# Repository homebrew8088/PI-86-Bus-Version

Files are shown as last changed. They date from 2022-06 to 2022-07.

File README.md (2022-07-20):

# PI-86-Bus-Version
8088 V20 Raspberry Pi "hat"
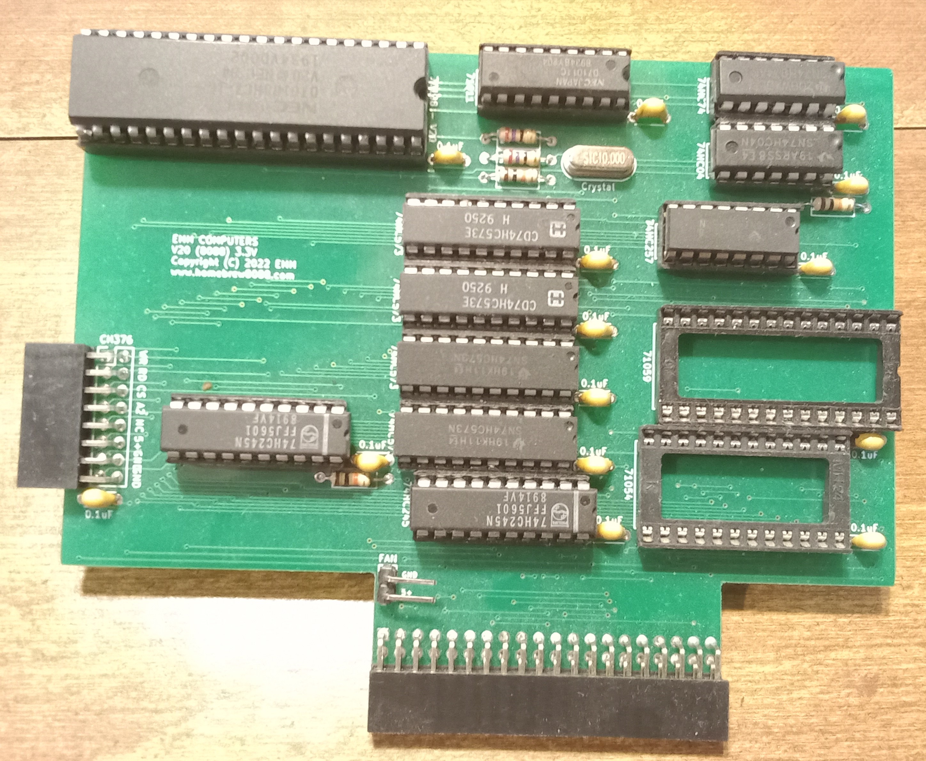
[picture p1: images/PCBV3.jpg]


\
\
This is a repository for my 8088 Raspberry Pi "hat" This is the 3rd version of this project and is quite different than previous versions. The intent was to achieve faster processing speeds by allowing the 8088 to run at its own speed. 

**Homepage**\
https://www.homebrew8088.com/

**Join the discussion group on Discord**\
https://discord.gg/AswNqwpRGP

**eBay store**\
http://www.ebay.com/sch/emil6190/m.html

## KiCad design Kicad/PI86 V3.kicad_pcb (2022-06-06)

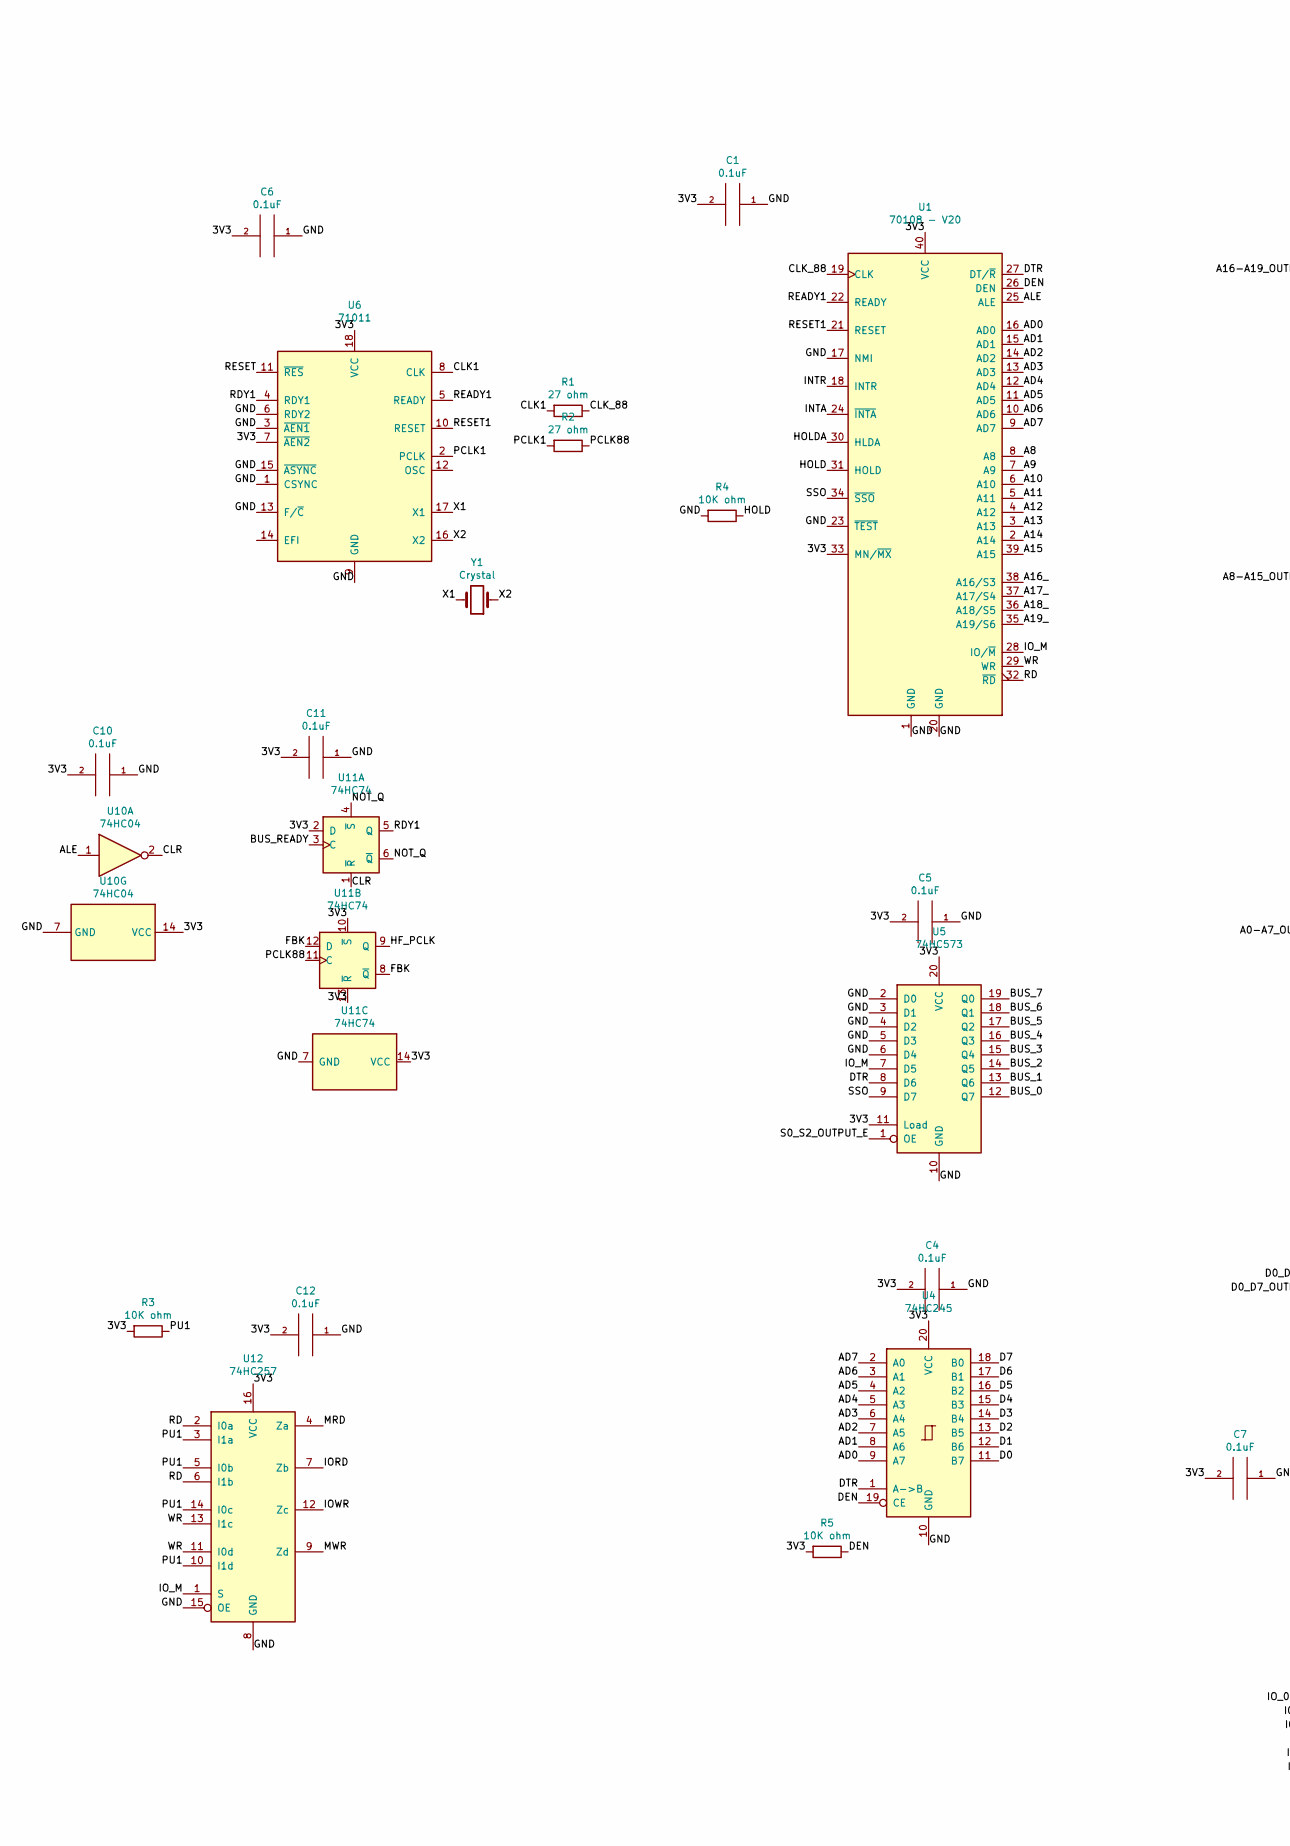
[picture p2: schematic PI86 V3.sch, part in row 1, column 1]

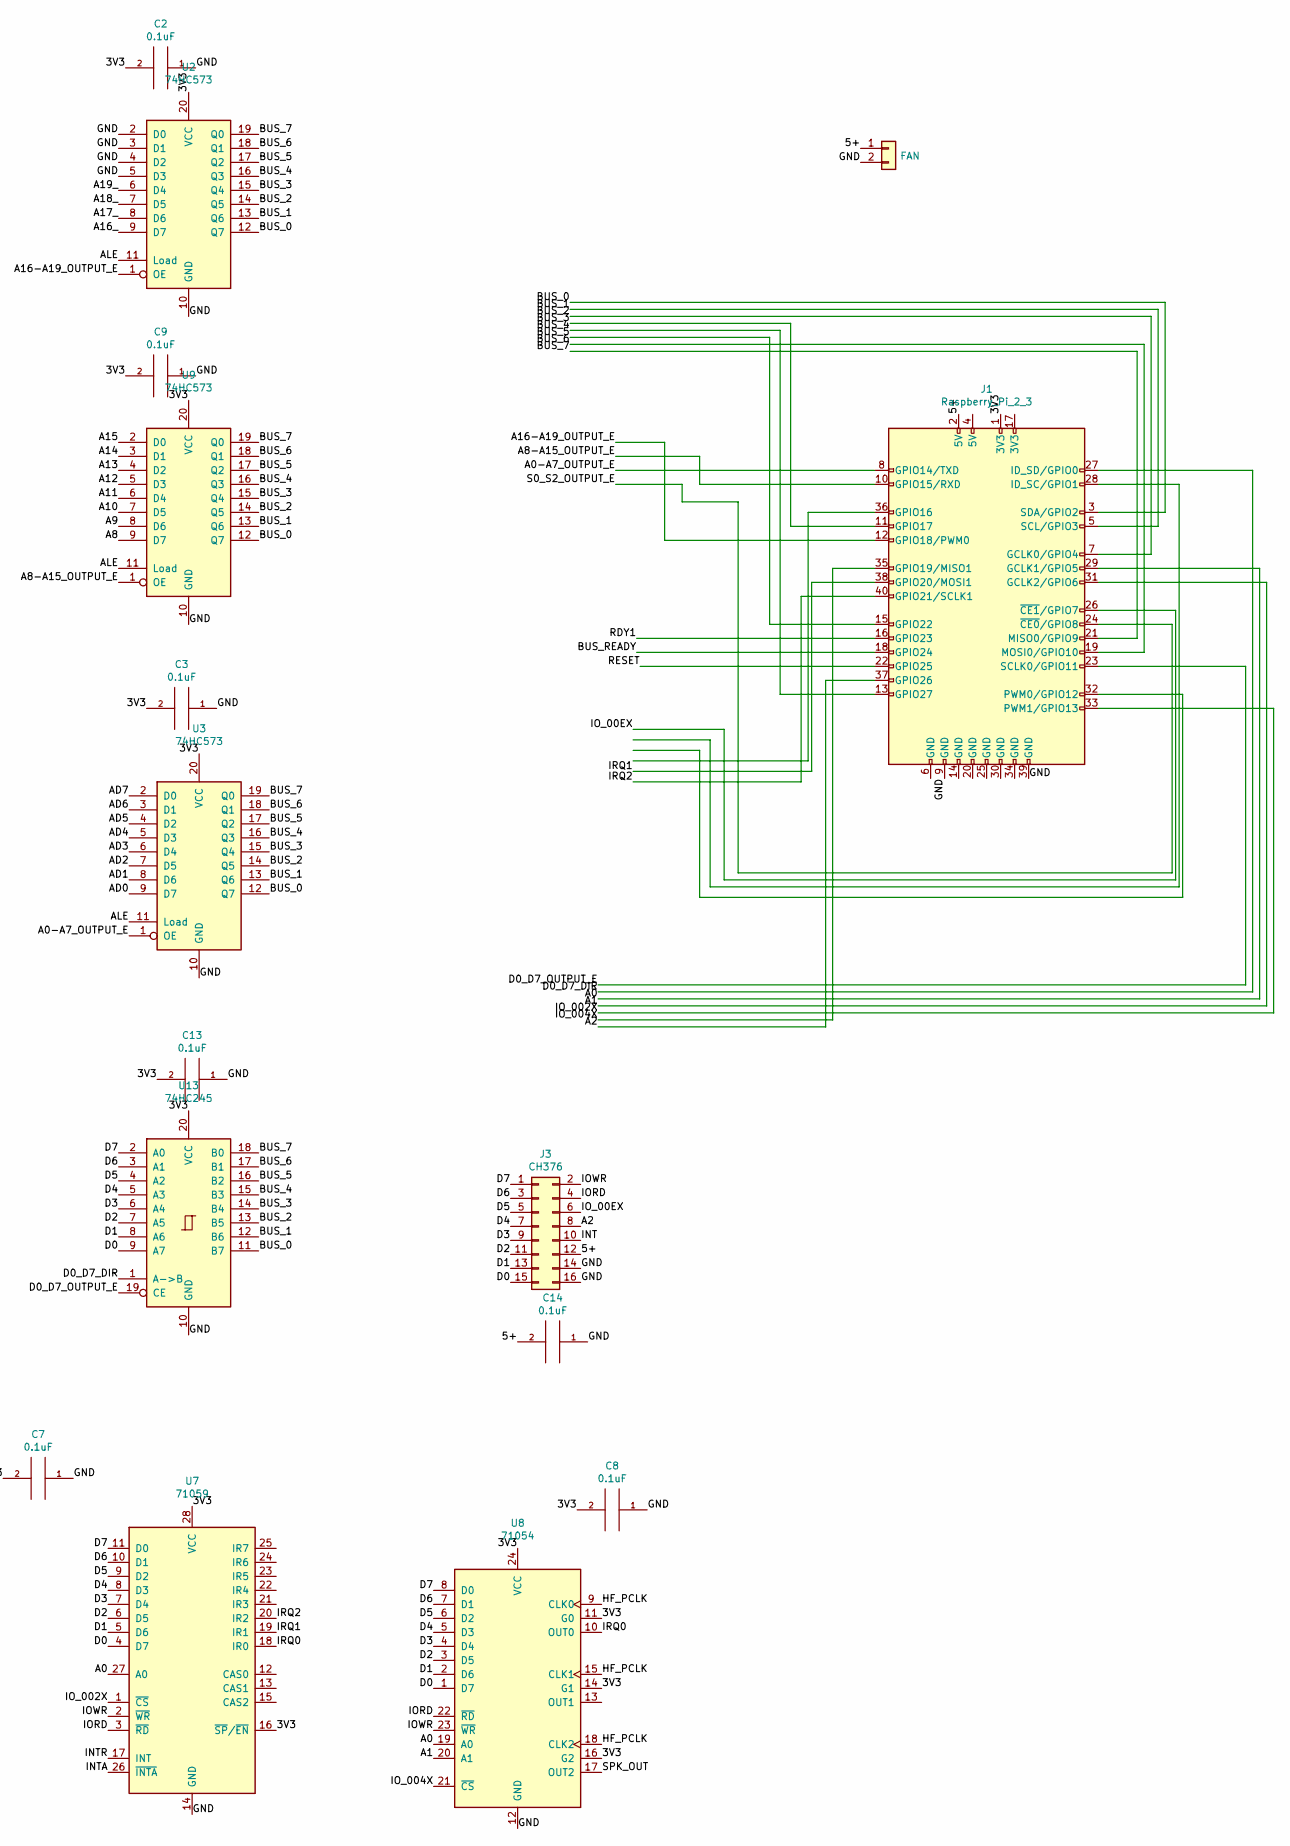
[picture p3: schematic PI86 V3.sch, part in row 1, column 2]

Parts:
C1, C2, C3, C4, C5, C6, C7, C8, C9, C10, C11, C12, C13, C14: 0.1uF; C_Disc_D4.3mm_W1.9mm_P5.00mm
J1: Raspberry_Pi_2_3; PinHeader_2x20_P2.54mm_Vertical
J2: FAN; PinHeader_1x02_P2.54mm_Vertical
J3: CH376; PinHeader_2x08_P2.54mm_Vertical
R1, R2: 27 ohm; R_Axial_DIN0207_L6.3mm_D2.5mm_P10.16mm_Horizontal
R3, R4, R5: 10K ohm; R_Axial_DIN0207_L6.3mm_D2.5mm_P10.16mm_Horizontal
U1: 70108 - V20; DIP-40_W15.24mm
U2, U3, U5, U9: 74HC573; DIP-20_W7.62mm
U4, U13: 74HC245; DIP-20_W7.62mm
U6: 71011; DIP-18_W7.62mm
U7: 71059; DIP-28_W15.24mm
U8: 71054; DIP-24_W15.24mm
U10: 74HC04; DIP-14_W7.62mm
U11: 74HC74; DIP-14_W7.62mm
U12: 74HC257; DIP-16_W7.62mm
Y1: Crystal; Crystal_HC18-U_Vertical

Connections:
/3V3: C1.2, C2.2, C3.2, C4.2, C5.2, C6.2, C7.2, C8.2, C9.2, C10.2, C11.2, C12.2, C13.2, J1.1 (3V3), R3.2, R5.2, U1.33 (MN/~MX~), U1.40 (VCC), U2.20 (VCC), U3.20 (VCC), U4.20 (VCC), U5.11 (Load), U5.20 (VCC), U6.7 (~AEN2~), U6.18 (VCC), U7.16 (~SP~/~EN~), U7.28 (VCC), U8.11 (G0), U8.14 (G1), U8.16 (G2), U8.24 (VCC), U9.20 (VCC), U10.14 (VCC), U11.2 (D), U11.10 (~S), U11.13 (~R), U11.14 (VCC), U12.16 (VCC), U13.20 (VCC)
/5+: C14.2, J1.2 (5V), J2.1, J3.12
/A0: J1.29 (GCLK1/GPIO5), U7.27 (A0), U8.19 (A0)
/A0-A7_OUTPUT_E: J1.8 (GPIO14/TXD), U3.1 (OE)
/A1: J1.31 (GCLK2/GPIO6), U8.20 (A1)
/A2: J1.37 (GPIO26), J3.8
/A8: U1.8 (A8), U9.9 (D7)
/A8-A15_OUTPUT_E: J1.10 (GPIO15/RXD), U9.1 (OE)
/A9: U1.7 (A9), U9.8 (D6)
/A10: U1.6 (A10), U9.7 (D5)
/A11: U1.5 (A11), U9.6 (D4)
/A12: U1.4 (A12), U9.5 (D3)
/A13: U1.3 (A13), U9.4 (D2)
/A14: U1.2 (A14), U9.3 (D1)
/A15: U1.39 (A15), U9.2 (D0)
/A16-A19_OUTPUT_E: J1.12 (GPIO18/PWM0), U2.1 (OE)
/A16_: U1.38 (A16/S3), U2.9 (D7)
/A17_: U1.37 (A17/S4), U2.8 (D6)
/A18_: U1.36 (A18/S5), U2.7 (D5)
/A19_: U1.35 (A19/S6), U2.6 (D4)
/AD0: U1.16 (AD0), U3.9 (D7), U4.9 (A7)
/AD1: U1.15 (AD1), U3.8 (D6), U4.8 (A6)
/AD2: U1.14 (AD2), U3.7 (D5), U4.7 (A5)
/AD3: U1.13 (AD3), U3.6 (D4), U4.6 (A4)
/AD4: U1.12 (AD4), U3.5 (D3), U4.5 (A3)
/AD5: U1.11 (AD5), U3.4 (D2), U4.4 (A2)
/AD6: U1.10 (AD6), U3.3 (D1), U4.3 (A1)
/AD7: U1.9 (AD7), U3.2 (D0), U4.2 (A0)
/ALE: U1.25 (ALE), U2.11 (Load), U3.11 (Load), U9.11 (Load), U10.1
/BUS_0: J1.3 (SDA/GPIO2), U2.12 (Q7), U3.12 (Q7), U5.12 (Q7), U9.12 (Q7), U13.11 (B7)
/BUS_1: J1.5 (SCL/GPIO3), U2.13 (Q6), U3.13 (Q6), U5.13 (Q6), U9.13 (Q6), U13.12 (B6)
/BUS_2: J1.7 (GCLK0/GPIO4), U2.14 (Q5), U3.14 (Q5), U5.14 (Q5), U9.14 (Q5), U13.13 (B5)
/BUS_3: J1.11 (GPIO17), U2.15 (Q4), U3.15 (Q4), U5.15 (Q4), U9.15 (Q4), U13.14 (B4)
/BUS_4: J1.13 (GPIO27), U2.16 (Q3), U3.16 (Q3), U5.16 (Q3), U9.16 (Q3), U13.15 (B3)
/BUS_5: J1.15 (GPIO22), U2.17 (Q2), U3.17 (Q2), U5.17 (Q2), U9.17 (Q2), U13.16 (B2)
/BUS_6: J1.19 (MOSI0/GPIO10), U2.18 (Q1), U3.18 (Q1), U5.18 (Q1), U9.18 (Q1), U13.17 (B1)
/BUS_7: J1.21 (MISO0/GPIO9), U2.19 (Q0), U3.19 (Q0), U5.19 (Q0), U9.19 (Q0), U13.18 (B0)
/BUS_READY: J1.18 (GPIO24), U11.3 (C)
/CLK1: R1.2, U6.8 (CLK)
/CLK_88: R1.1, U1.19 (CLK)
/CLR: U10.2, U11.1 (~R)
/D0: J3.15, U4.11 (B7), U7.4 (D7), U8.1 (D7), U13.9 (A7)
/D0_D7_DIR: J1.27 (ID_SD/GPIO0), U13.1 (A->B)
/D0_D7_OUTPUT_E: J1.23 (SCLK0/GPIO11), U13.19 (CE)
/D1: J3.13, U4.12 (B6), U7.5 (D6), U8.2 (D6), U13.8 (A6)
/D2: J3.11, U4.13 (B5), U7.6 (D5), U8.3 (D5), U13.7 (A5)
/D3: J3.9, U4.14 (B4), U7.7 (D4), U8.4 (D4), U13.6 (A4)
/D4: J3.7, U4.15 (B3), U7.8 (D3), U8.5 (D3), U13.5 (A3)
/D5: J3.5, U4.16 (B2), U7.9 (D2), U8.6 (D2), U13.4 (A2)
/D6: J3.3, U4.17 (B1), U7.10 (D1), U8.7 (D1), U13.3 (A1)
/D7: J3.1, U4.18 (B0), U7.11 (D0), U8.8 (D0), U13.2 (A0)
/DEN: R5.1, U1.26 (DEN), U4.19 (CE)
/DTR: U1.27 (DT/~R~), U4.1 (A->B), U5.8 (D6)
/FBK: U11.8 (~Q), U11.12 (D)
/GND: C1.1, C2.1, C3.1, C4.1, C5.1, C6.1, C7.1, C8.1, C9.1, C10.1, C11.1, C12.1, C13.1, C14.1, J1.9 (GND), J1.39 (GND), J2.2, J3.14, J3.16, R4.2, U1.1 (GND), U1.17 (NMI), U1.20 (GND), U1.23 (~TEST~), U2.2 (D0), U2.3 (D1), U2.4 (D2), U2.5 (D3), U2.10 (GND), U3.10 (GND), U4.10 (GND), U5.2 (D0), U5.3 (D1), U5.4 (D2), U5.5 (D3), U5.6 (D4), U5.10 (GND), U6.1 (CSYNC), U6.3 (~AEN1~), U6.6 (RDY2), U6.9 (GND), U6.13 (F/~C~), U6.15 (~ASYNC~), U7.14 (GND), U8.12 (GND), U9.10 (GND), U10.7 (GND), U11.7 (GND), U12.8 (GND), U12.15 (OE), U13.10 (GND)
/HF_PCLK: U8.9 (CLK0), U8.15 (CLK1), U8.18 (CLK2), U11.9 (Q)
/HOLD: R4.1, U1.31 (HOLD)
/HOLDA: U1.30 (HLDA)
/INT: J3.10
/INTA: U1.24 (~INTA~), U7.26 (~INTA~)
/INTR: U1.18 (INTR), U7.17 (INT)
/IORD: J3.4, U7.3 (~RD~), U8.22 (~RD~), U12.7 (Zb)
/IOWR: J3.2, U7.2 (~WR~), U8.23 (~WR~), U12.12 (Zc)
/IO_00EX: J1.26 (~CE1~/GPIO7), J3.6
/IO_002X: J1.33 (PWM1/GPIO13), U7.1 (~CS~)
/IO_004X: J1.35 (GPIO19/MISO1), U8.21 (~CS~)
/IO_M: U1.28 (IO/~M~), U5.7 (D5), U12.1 (S)
/IRQ0: U7.18 (IR0), U8.10 (OUT0)
/IRQ1: J1.38 (GPIO20/MOSI1), U7.19 (IR1)
/IRQ2: J1.40 (GPIO21/SCLK1), U7.20 (IR2)
/MRD: U12.4 (Za)
/MWR: U12.9 (Zd)
/NOT_Q: U11.4 (~S), U11.6 (~Q)
/PCLK1: R2.2, U6.2 (PCLK)
/PCLK88: R2.1, U11.11 (C)
/PU1: R3.1, U12.3 (I1a), U12.5 (I0b), U12.10 (I1d), U12.14 (I0c)
/RD: U1.32 (~RD~), U12.2 (I0a), U12.6 (I1b)
/RDY1: J1.16 (GPIO23), U6.4 (RDY1), U11.5 (Q)
/READY1: U1.22 (READY), U6.5 (READY)
/RESET: J1.22 (GPIO25), U6.11 (~RES~)
/RESET1: U1.21 (RESET), U6.10 (RESET)
/S0_S2_OUTPUT_E: J1.24 (~CE0~/GPIO8), U5.1 (OE)
/SPK_OUT: U8.17 (OUT2)
/SSO: U1.34 (~SSO~), U5.9 (D7)
/WR: U1.29 (WR), U12.11 (I0d), U12.13 (I1c)
/X1: U6.17 (X1), Y1.2
/X2: U6.16 (X2), Y1.1

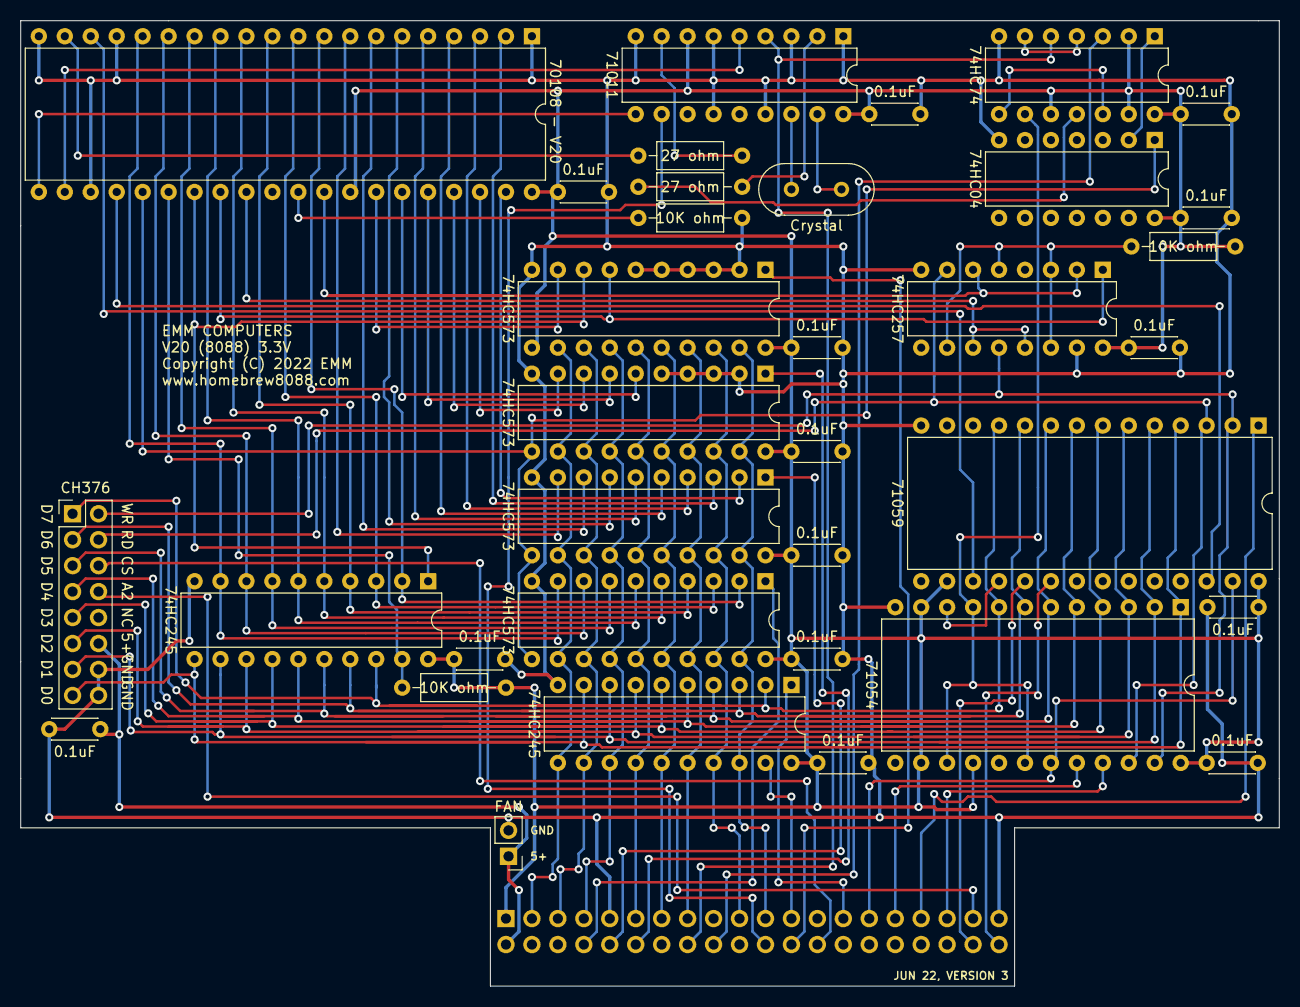
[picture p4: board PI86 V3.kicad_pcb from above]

Board: 2 copper layers, 123.2 x 94.5 mm, 36 parts (1 on the bottom side), 82 nets.

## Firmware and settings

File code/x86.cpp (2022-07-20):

#include "x86.h"

unsigned char RAM[0x100000];
unsigned char IO[0x10000];

//////////////////////////////
//System Bus
///////////////////////////////
void Bus_Direction_IN()
{
    pinMode(BUS_0, INPUT);  
    pinMode(BUS_1, INPUT);
    pinMode(BUS_2, INPUT);
    pinMode(BUS_3, INPUT);
    pinMode(BUS_4, INPUT);
    pinMode(BUS_5, INPUT);
    pinMode(BUS_6, INPUT);
    pinMode(BUS_7, INPUT);
}
void Bus_Direction_OUT()
{
    pinMode(BUS_0, OUTPUT);  
    pinMode(BUS_1, OUTPUT);
    pinMode(BUS_2, OUTPUT);
    pinMode(BUS_3, OUTPUT);
    pinMode(BUS_4, OUTPUT);
    pinMode(BUS_5, OUTPUT);
    pinMode(BUS_6, OUTPUT);
    pinMode(BUS_7, OUTPUT);
}
int Read_Control()
{
   int Control;
   Bus_Direction_IN();
   digitalWrite(D0_D7_OUTPUT_E, HIGH);
   digitalWrite(S0_S2_OUTPUT_E, LOW);
   Control = digitalRead(BUS_0);
   Control = Control + (digitalRead(BUS_1) << 1);
   Control = Control + (digitalRead(BUS_2) << 2);
   Control = Control + (digitalRead(BUS_3) << 3);
   digitalWrite(S0_S2_OUTPUT_E, HIGH);
	return Control;
}
int Read_Address()
{
   int Address;
   Bus_Direction_IN();
   digitalWrite(D0_D7_OUTPUT_E, HIGH);
   digitalWrite(A0_A7_OUTPUT_E, LOW);
   Address = digitalRead(BUS_0);
   Address = Address + (digitalRead(BUS_1) << 1);
   Address = Address + (digitalRead(BUS_2) << 2);
   Address = Address + (digitalRead(BUS_3) << 3);
   Address = Address + (digitalRead(BUS_4) << 4);
   Address = Address + (digitalRead(BUS_5) << 5);
   Address = Address + (digitalRead(BUS_6) << 6);
   Address = Address + (digitalRead(BUS_7) << 7);
   digitalWrite(A0_A7_OUTPUT_E, HIGH);
   digitalWrite(A8_A15_OUTPUT_E, LOW);
   Address = Address + (digitalRead(BUS_0) << 8);
   Address = Address + (digitalRead(BUS_1) << 9);
   Address = Address + (digitalRead(BUS_2) << 10);
   Address = Address + (digitalRead(BUS_3) << 11);
   Address = Address + (digitalRead(BUS_4) << 12);
   Address = Address + (digitalRead(BUS_5) << 13);
   Address = Address + (digitalRead(BUS_6) << 14);
   Address = Address + (digitalRead(BUS_7) << 15);
   digitalWrite(A8_A15_OUTPUT_E, HIGH);
   digitalWrite(A16_A19_OUTPUT_E, LOW);
   Address = Address + (digitalRead(BUS_0) << 16);
   Address = Address + (digitalRead(BUS_1) << 17);
   Address = Address + (digitalRead(BUS_2) << 18);
   Address = Address + (digitalRead(BUS_3) << 19);
   digitalWrite(A16_A19_OUTPUT_E, HIGH);
   return Address;
}
void Write_Data(char Byte)
{
	Bus_Direction_OUT();
	digitalWrite(D0_D7_OUTPUT_E, LOW);
	digitalWrite(D0_D7_DIR, LOW);
	digitalWrite(BUS_0, Byte & 1); 
	digitalWrite(BUS_1,(Byte >> 1) & 1); 
	digitalWrite(BUS_2, (Byte >> 2) & 1); 
	digitalWrite(BUS_3, (Byte >> 3) & 1); 
	digitalWrite(BUS_4, (Byte >> 4) & 1); 
	digitalWrite(BUS_5, (Byte >> 5) & 1); 
	digitalWrite(BUS_6, (Byte >> 6) & 1); 
	digitalWrite(BUS_7, (Byte >> 7) & 1); 
}
char Read_Data()
{
	Bus_Direction_IN();
	digitalWrite(D0_D7_OUTPUT_E, LOW);
	digitalWrite(D0_D7_DIR, HIGH);
	char ret;
	ret = digitalRead(BUS_0);
	ret = ret + (digitalRead(BUS_1) << 1);
	ret = ret + (digitalRead(BUS_2) << 2);
	ret = ret + (digitalRead(BUS_3) << 3);
	ret = ret + (digitalRead(BUS_4) << 4);
	ret = ret + (digitalRead(BUS_5) << 5);
	ret = ret + (digitalRead(BUS_6) << 6);
	ret = ret + (digitalRead(BUS_7) << 7);
	digitalWrite(D0_D7_OUTPUT_E, HIGH);
	return ret;
}
//Sets up Raspberry PI pins in the begining 
void Setup()
{
   Stop_Flag = false;
   wiringPiSetup();
   pinMode(D0_D7_OUTPUT_E, OUTPUT);  
   pinMode(D0_D7_DIR, OUTPUT);  
   pinMode(PIN_A0, OUTPUT);  
   pinMode(PIN_A1, OUTPUT);  
   pinMode(PORT_20_CS, OUTPUT);  
   pinMode(PORT_40_CS, OUTPUT);  
   pinMode(PIN_A2, OUTPUT);  

   pinMode(A0_A7_OUTPUT_E, OUTPUT);  
   pinMode(A8_A15_OUTPUT_E, OUTPUT);  
   pinMode(A16_A19_OUTPUT_E, OUTPUT); 

   pinMode(READY, INPUT); 
   pinMode(BUS_READY, OUTPUT);  
   pinMode(RESET, OUTPUT);  

   pinMode(S0_S2_OUTPUT_E, OUTPUT);  
   pinMode(PORT_E0_CS, OUTPUT);  

   pinMode(IRQ1, OUTPUT);  
   pinMode(IRQ2, OUTPUT);  
   
   //Address Latched and Data bus
   digitalWrite(D0_D7_OUTPUT_E, HIGH);
   digitalWrite(A0_A7_OUTPUT_E, HIGH);
   digitalWrite(A8_A15_OUTPUT_E, HIGH);
   digitalWrite(A16_A19_OUTPUT_E, HIGH);
   //Control Bus
   digitalWrite(S0_S2_OUTPUT_E, HIGH);
   //Onboard IO's
   digitalWrite(PORT_20_CS, HIGH);
   digitalWrite(PORT_40_CS, HIGH);
   digitalWrite(PORT_E0_CS, HIGH);
   //IRQ's
   digitalWrite(IRQ1, LOW);
   digitalWrite(IRQ2, LOW);
   //Ready
   digitalWrite(BUS_READY, LOW);
   //Reset
   digitalWrite(RESET, LOW);
   sleep(.1);
   digitalWrite(RESET, HIGH);
}
void Ready()
{
   digitalWrite(BUS_READY, HIGH);
   digitalWrite(BUS_READY, HIGH);
   digitalWrite(BUS_READY, HIGH);
   digitalWrite(BUS_READY, HIGH);
   digitalWrite(BUS_READY, LOW);
   digitalWrite(BUS_READY, LOW);
   digitalWrite(BUS_READY, LOW);
   digitalWrite(BUS_READY, LOW);
	//usleep(.01);	
}
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

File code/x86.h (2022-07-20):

#ifndef X86_H
#define X86_H


#define BUS_0   8
#define BUS_1   9
#define BUS_2   7
#define BUS_3   0
#define BUS_4   2
#define BUS_5   3
#define BUS_6   12
#define BUS_7   13

#define D0_D7_OUTPUT_E 	14
#define D0_D7_DIR 		30
#define PIN_A0			21
#define PIN_A1			22
#define PORT_20_CS		23	
#define PORT_40_CS		24
#define PIN_A2			25

#define A0_A7_OUTPUT_E	15
#define A8_A15_OUTPUT_E	16
#define A16_A19_OUTPUT_E 1

#define READY			4
#define BUS_READY		5
#define RESET			6

#define S0_S2_OUTPUT_E	10
#define PORT_E0_CS		11

#define IRQ1			28
#define IRQ2			29


#include <wiringPi.h>
#include <string>
#include <thread>
#include <unistd.h>
#include <fstream> 

using namespace std;

static bool Stop_Flag;


void Reset();	
void Start();
void Load_Bios(string Bios_file);
//Memory
void Write_Memory_Array(unsigned long long int Address, char code_for_8088[], int Length);
void Read_Memory_Array(unsigned long long int Address, char* char_Array, int Length);
void Write_Memory_Byte(unsigned long long int Address, char byte_for_8088);
char Read_Memory_Byte(unsigned long long int Address);		
void Write_Memory_Word(unsigned long long int Address, unsigned short int word_for_8088);
//IO

void Write_IO_Byte(unsigned long long int Address, char byte_for_8088);
char Read_IO_Byte(unsigned long long int Address);
void Write_IO_Word(unsigned long long int Address, unsigned short int word_for_8088);

//INT


#endif

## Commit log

2022-06-06 Initial push
    [PI86 V3-B_Cu.gbr, PI86 V3-B_Mask.gbr, PI86 V3-B_Paste.gbr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]
2022-07-20 Create PCB V3.jpg

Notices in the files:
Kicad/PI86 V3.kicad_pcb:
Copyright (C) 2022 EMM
